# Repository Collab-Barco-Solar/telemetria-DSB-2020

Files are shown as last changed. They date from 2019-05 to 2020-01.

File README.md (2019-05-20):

# telemetria-barco
The codes of a competition boat

Using a TTGO T-Beam Esp 32 with LoRa communication, WiFi, Bluetooth and GPS capabilities.

This repository contains the codes of a project in progress

The Arduino LoRa library utilized is the sandeepmistry arduino LoRa at: https://github.com/sandeepmistry/arduino-LoRa
The ESP32 Arduino library utilized is the espressif arduino-esp32 at: https://github.com/espressif/arduino-esp32 with a guide on how to run it here: https://github.com/espressif/arduino-esp32/blob/master/docs/arduino-ide/boards_manager.md

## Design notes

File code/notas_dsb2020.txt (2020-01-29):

- LEMBRAR DE FAZER TABELA DE RENDIMENTOS DO MOTOR E BUSCAR  MAXIMO RENDIMENTO TEÓRICO;
- Jogar a funcao de desenhar numeros grandes numa biblioteca;
- Descobrir a expressao que descreve carga na bateria em funcao da tensao;
- Criar nocao de tempo para o controlador por biblioteca;

Conector medicoes caixa de circuitos:

- Bat aux - amarelo.
- Bat banco - laranja
- PV in - vermelho

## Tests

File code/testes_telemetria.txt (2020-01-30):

Notas TELEMETRIA (TESTES)

* FUNCIONAMENTO DO ADS1115 (pode ter morrido)
    - Conferir a funcao BatteryCurrentRead();
    - MotorCurrentRead();

* POTENCIOMETRO
    - Conferir se chega 5V do motor (caso nao, ajustar valor setado em codigo);

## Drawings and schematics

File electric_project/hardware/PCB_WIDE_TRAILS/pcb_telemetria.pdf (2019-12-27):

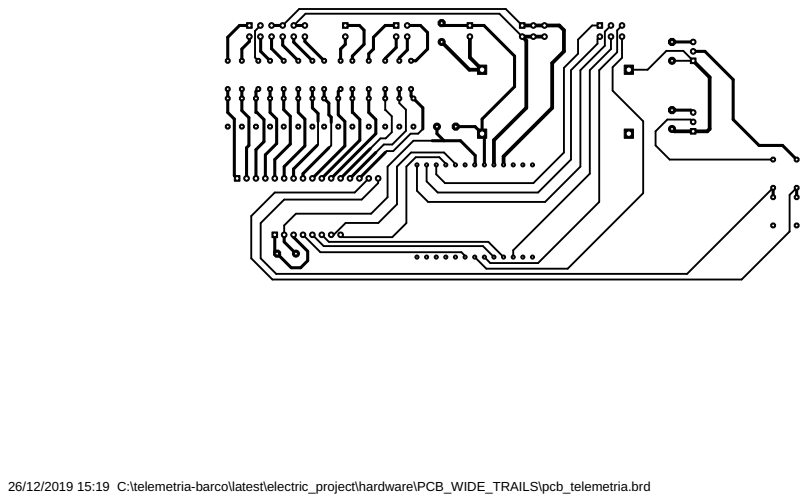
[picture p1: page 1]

26/12/2019 15:19 C:\telemetria-barco\latest\electric_project\hardware\PCB_WIDE_TRAILS\pcb_telemetria.brd

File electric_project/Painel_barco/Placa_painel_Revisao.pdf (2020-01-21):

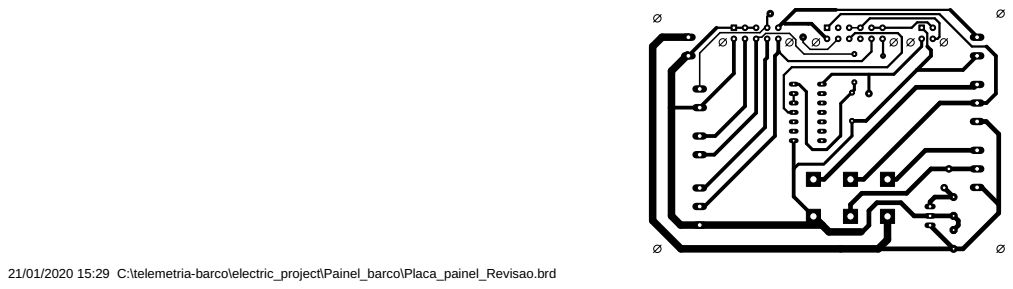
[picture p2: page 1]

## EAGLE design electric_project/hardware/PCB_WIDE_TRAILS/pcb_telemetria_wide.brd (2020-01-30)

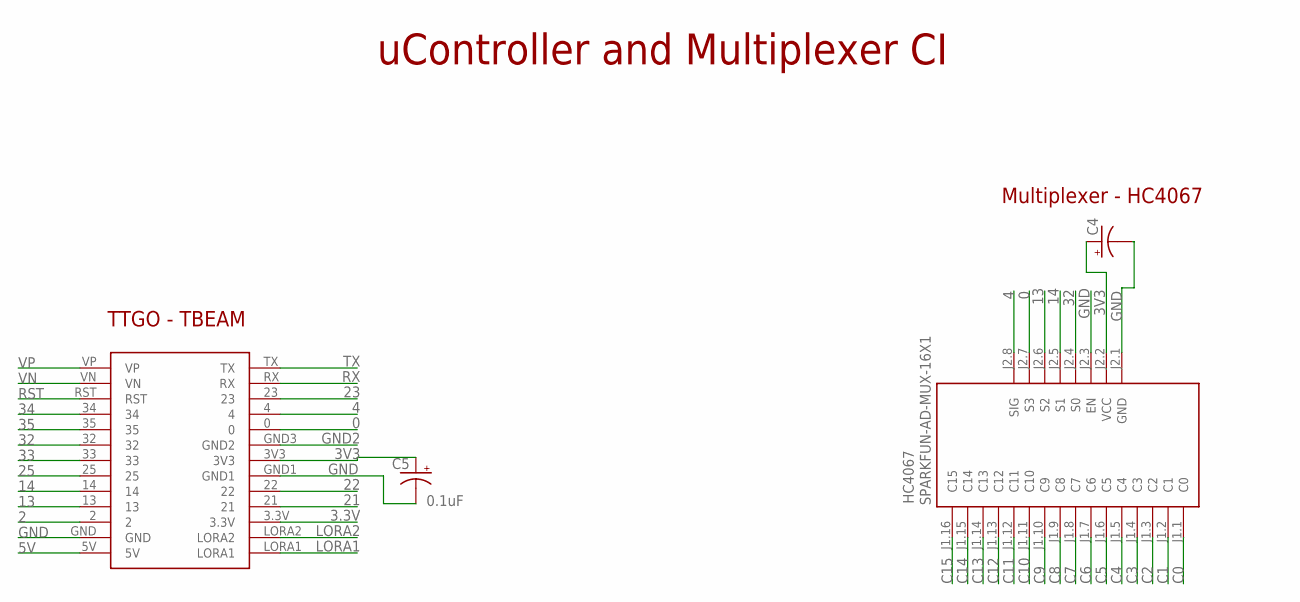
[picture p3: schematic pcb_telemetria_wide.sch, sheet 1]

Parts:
C4: CPOL-USE5-5; E5-5
C5: 0.1uF; E5-5
HC4067: SPARKFUN-AD-MUX-16X1
U$1: TTGOBEAM

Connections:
0: HC4067.J2.7 (S3), U$1.0
2: U$1.2; also elsewhere on the board
3.3V: U$1.3.3V
3V3: C4.+, C5.+, HC4067.J2.2 (VCC), U$1.3V3
4: HC4067.J2.8 (SIG), U$1.4
5V: U$1.5V
13: HC4067.J2.6 (S2), U$1.13
14: HC4067.J2.5 (S1), U$1.14
21: U$1.21; also elsewhere on the board
22: U$1.22; also elsewhere on the board
23: U$1.23; also elsewhere on the board
25: U$1.25; also elsewhere on the board
32: HC4067.J2.4 (S0), U$1.32
33: U$1.33; also elsewhere on the board
34: U$1.34
35: U$1.35
C0: HC4067.J1.1 (C0); also elsewhere on the board
C1: HC4067.J1.2 (C1); also elsewhere on the board
C2: HC4067.J1.3 (C2); also elsewhere on the board
C3: HC4067.J1.4 (C3); also elsewhere on the board
C4: HC4067.J1.5 (C4); also elsewhere on the board
C5: HC4067.J1.6 (C5); also elsewhere on the board
C6: HC4067.J1.7 (C6); also elsewhere on the board
C7: HC4067.J1.8 (C7); also elsewhere on the board
C8: HC4067.J1.9 (C8); also elsewhere on the board
C9: HC4067.J1.10 (C9); also elsewhere on the board
C10: HC4067.J1.11 (C10); also elsewhere on the board
C11: HC4067.J1.12 (C11); also elsewhere on the board
C12: HC4067.J1.13 (C12); also elsewhere on the board
C13: HC4067.J1.14 (C13); also elsewhere on the board
C14: HC4067.J1.15 (C14); also elsewhere on the board
C15: HC4067.J1.16 (C15); also elsewhere on the board
GND: C4.-, C5.-, HC4067.J2.1 (GND), HC4067.J2.3 (EN), U$1.GND, U$1.GND1; also elsewhere on the board
GND2: U$1.GND3 (GND2)
LORA1: U$1.LORA1
LORA2: U$1.LORA2
RST: U$1.RST
RX: U$1.RX; also elsewhere on the board
TX: U$1.TX; also elsewhere on the board
VN: U$1.VN
VP: U$1.VP

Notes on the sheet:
uController and Multiplexer CI
TTGO - TBEAM
Multiplexer - HC4067

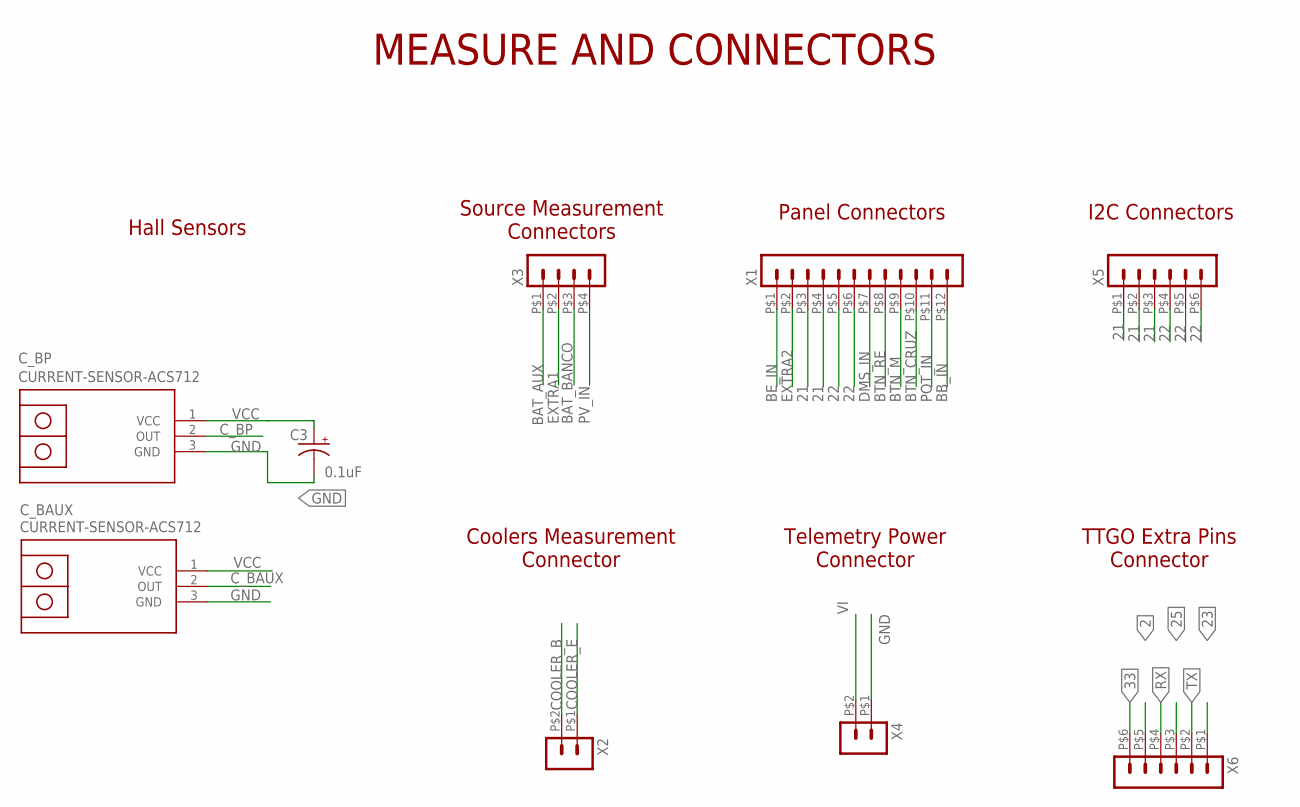
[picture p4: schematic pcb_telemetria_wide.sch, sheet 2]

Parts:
C3: 0.1uF; E5-5
C_BAUX: CURRENT-SENSOR-ACS712
C_BP: CURRENT-SENSOR-ACS712
X1: HEADER_POS12_43045-1212; 43045-1212
X2, X4: HEADER_POS2_43045-0212; 43045-0212
X3: HEADER_POS4_43045-0412; 43045-0412
X5, X6: HEADER_POS6_43045-0612; 43045-0612

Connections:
2: X6.P$5 (5); also elsewhere on the board
21: X1.P$3 (3), X1.P$4 (4), X5.P$1 (1), X5.P$2 (2), X5.P$3 (3); also elsewhere on the board
22: X1.P$5 (5), X1.P$6 (6), X5.P$4 (4), X5.P$5 (5), X5.P$6 (6); also elsewhere on the board
23: X6.P$1 (1); also elsewhere on the board
25: X6.P$3 (3); also elsewhere on the board
33: X6.P$6 (6); also elsewhere on the board
BAT_AUX: X3.P$1 (1); also elsewhere on the board
BAT_BANCO: X3.P$3 (3); also elsewhere on the board
BB_IN: X1.P$12 (12); also elsewhere on the board
BE_IN: X1.P$1 (1); also elsewhere on the board
BTN_CRUZ: X1.P$10 (10); also elsewhere on the board
BTN_M: X1.P$9 (9); also elsewhere on the board
BTN_RE: X1.P$8 (8); also elsewhere on the board
COOLER_B: X2.P$2 (2); also elsewhere on the board
COOLER_E: X2.P$1 (1); also elsewhere on the board
C_BAUX: C_BAUX.2 (OUT); also elsewhere on the board
C_BP: C_BP.2 (OUT); also elsewhere on the board
DMS_IN: X1.P$7 (7); also elsewhere on the board
EXTRA1: X3.P$2 (2); also elsewhere on the board
EXTRA2: X1.P$2 (2); also elsewhere on the board
GND: C3.-, C_BAUX.3 (GND), C_BP.3 (GND), X4.P$1 (1); also elsewhere on the board
POT_IN: X1.P$11 (11); also elsewhere on the board
PV_IN: X3.P$4 (4); also elsewhere on the board
RX: X6.P$4 (4); also elsewhere on the board
TX: X6.P$2 (2); also elsewhere on the board
VCC: C3.+, C_BAUX.1 (VCC), C_BP.1 (VCC); also elsewhere on the board
VI: X4.P$2 (2); also elsewhere on the board

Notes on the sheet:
MEASURE AND CONNECTORS
Hall Sensors
Source Measurement Connectors
I2C Connectors
Panel Connectors
Coolers Measurement Connector
Telemetry Power Connector
TTGO Extra Pins Connector

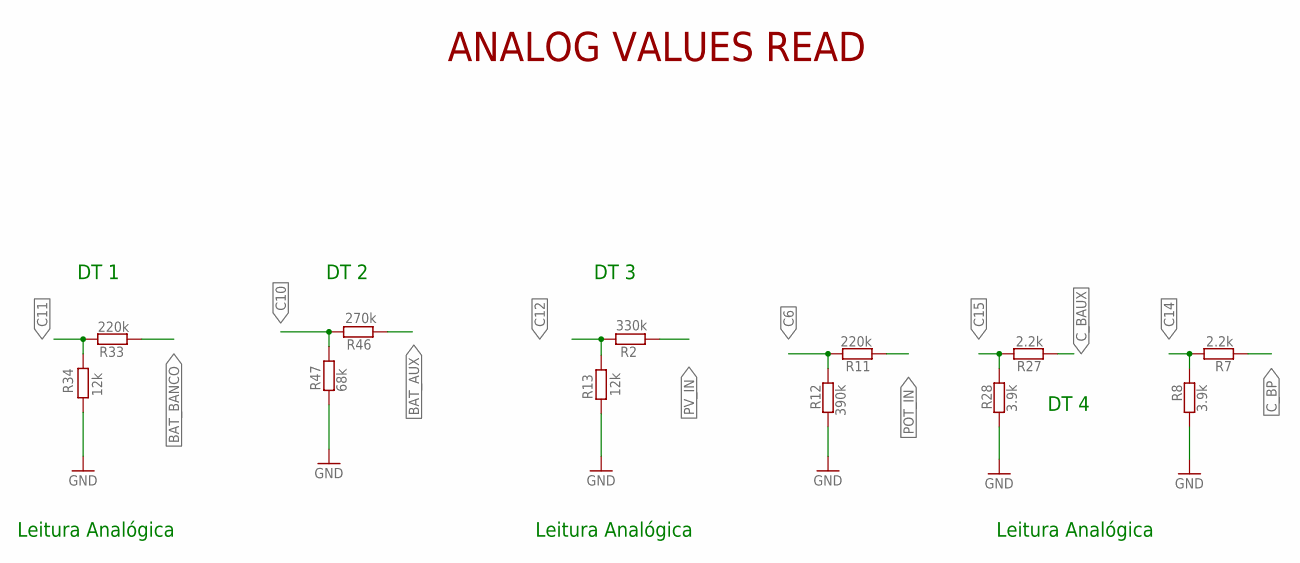
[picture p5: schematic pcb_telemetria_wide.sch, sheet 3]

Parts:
R2: 330k; 0204/7
R7, R27: 2.2k; 0204/7
R8, R28: 3.9k; 0204/7
R11, R33: 220k; 0204/7
R12: 390k; 0204/7
R13, R34: 12k; 0204/7
R46: 270k; 0204/7
R47: 68k; 0204/7

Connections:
BAT_AUX: R46.2; also elsewhere on the board
BAT_BANCO: R33.2; also elsewhere on the board
C6: R11.2, R12.1; also elsewhere on the board
C10: R46.1, R47.2; also elsewhere on the board
C11: R33.1, R34.2; also elsewhere on the board
C12: R2.1, R13.2; also elsewhere on the board
C14: R7.2, R8.1; also elsewhere on the board
C15: R27.2, R28.1; also elsewhere on the board
C_BAUX: R27.1; also elsewhere on the board
C_BP: R7.1; also elsewhere on the board
GND: R8.2, R12.2, R13.1, R28.2, R34.1, R47.1; also elsewhere on the board
POT_IN: R11.1; also elsewhere on the board
PV_IN: R2.2; also elsewhere on the board

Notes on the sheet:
ANALOG VALUES READ
Leitura Analógica
DT 1
DT 3
DT 4
DT 2

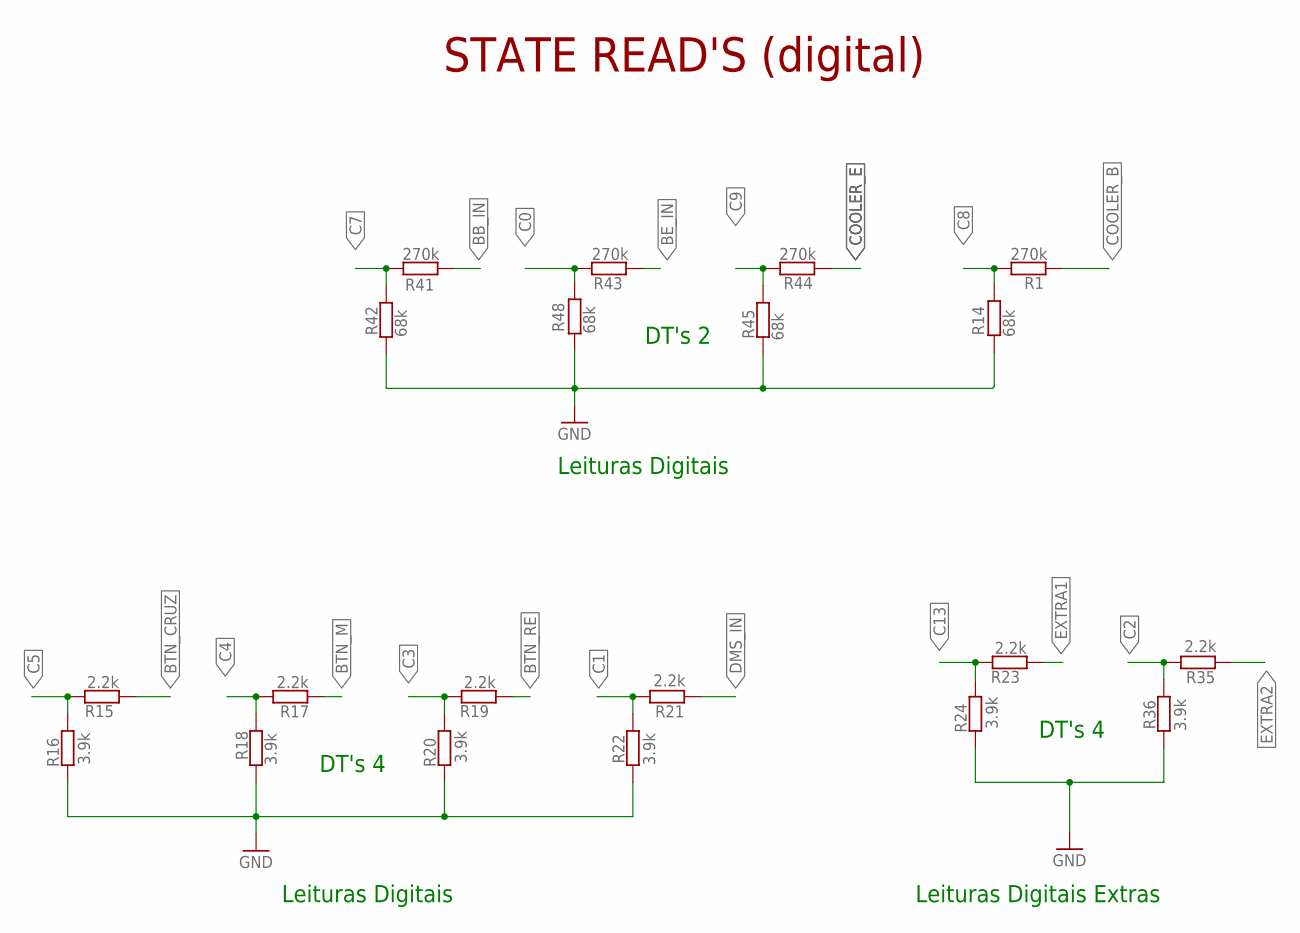
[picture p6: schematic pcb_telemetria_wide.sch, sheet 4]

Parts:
R1, R41, R43, R44: 270k; 0204/7
R14, R42, R45, R48: 68k; 0204/7
R15, R17, R19, R21, R23, R35: 2.2k; 0204/7
R16, R18, R20, R22, R24, R36: 3.9k; 0204/7

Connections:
BB_IN: R41.1; also elsewhere on the board
BE_IN: R43.2; also elsewhere on the board
BTN_CRUZ: R15.1; also elsewhere on the board
BTN_M: R17.2; also elsewhere on the board
BTN_RE: R19.1; also elsewhere on the board
C0: R43.1, R48.1; also elsewhere on the board
C1: R21.1, R22.2; also elsewhere on the board
C2: R35.1, R36.2; also elsewhere on the board
C3: R19.2, R20.1; also elsewhere on the board
C4: R17.1, R18.2; also elsewhere on the board
C5: R15.2, R16.1; also elsewhere on the board
C7: R41.2, R42.1; also elsewhere on the board
C8: R1.2, R14.2; also elsewhere on the board
C9: R44.2, R45.1; also elsewhere on the board
C13: R23.2, R24.1; also elsewhere on the board
COOLER_B: R1.1; also elsewhere on the board
COOLER_E: R44.1; also elsewhere on the board
DMS_IN: R21.2; also elsewhere on the board
EXTRA1: R23.1; also elsewhere on the board
EXTRA2: R35.2; also elsewhere on the board
GND: R14.1, R16.2, R18.1, R20.2, R22.1, R24.2, R36.1, R42.2, R45.2, R48.2; also elsewhere on the board

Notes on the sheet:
STATE READ'S (digital)
Leituras Digitais
DT's 2
Leituras Digitais Extras
DT's 4

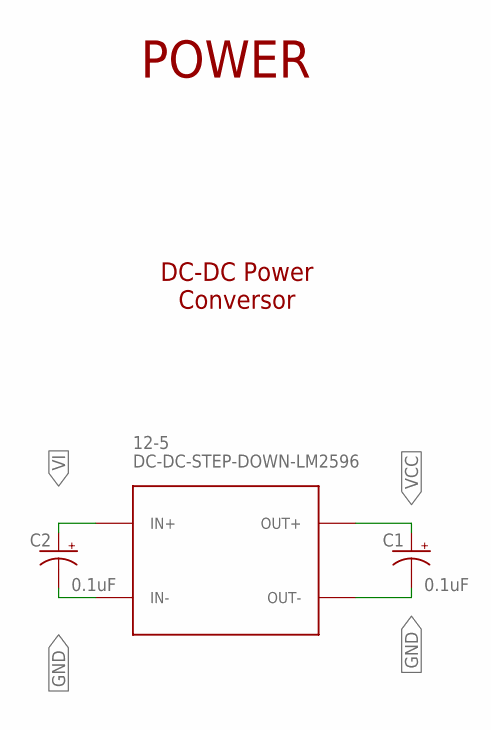
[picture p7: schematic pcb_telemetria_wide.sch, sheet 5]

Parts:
12-5: DC-DC-STEP-DOWN-LM2596
C1, C2: 0.1uF; E5-5

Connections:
GND: 12-5.IN-, 12-5.OUT-, C1.-, C2.-; also elsewhere on the board
VCC: 12-5.OUT+, C1.+; also elsewhere on the board
VI: 12-5.IN+, C2.+; also elsewhere on the board

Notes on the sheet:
POWER
DC-DC Power Conversor

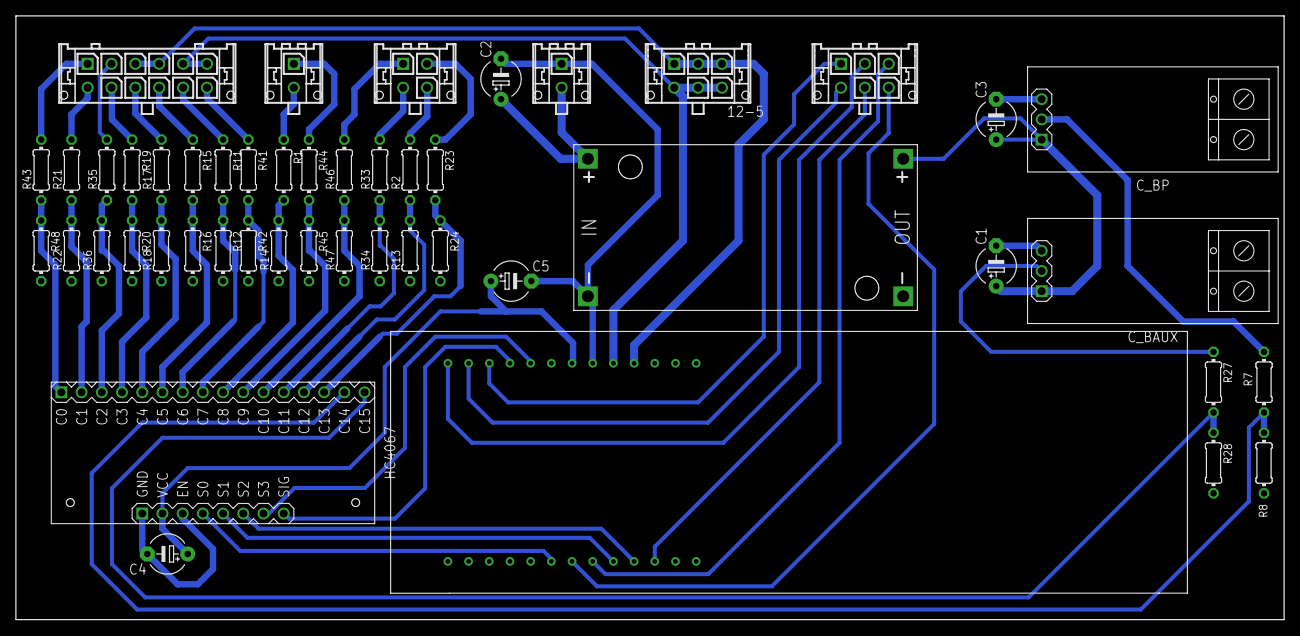
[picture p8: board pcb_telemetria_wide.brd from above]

Board: 2 copper layers, 159.4 x 75.9 mm, 48 parts (0 on the bottom side), 49 nets.

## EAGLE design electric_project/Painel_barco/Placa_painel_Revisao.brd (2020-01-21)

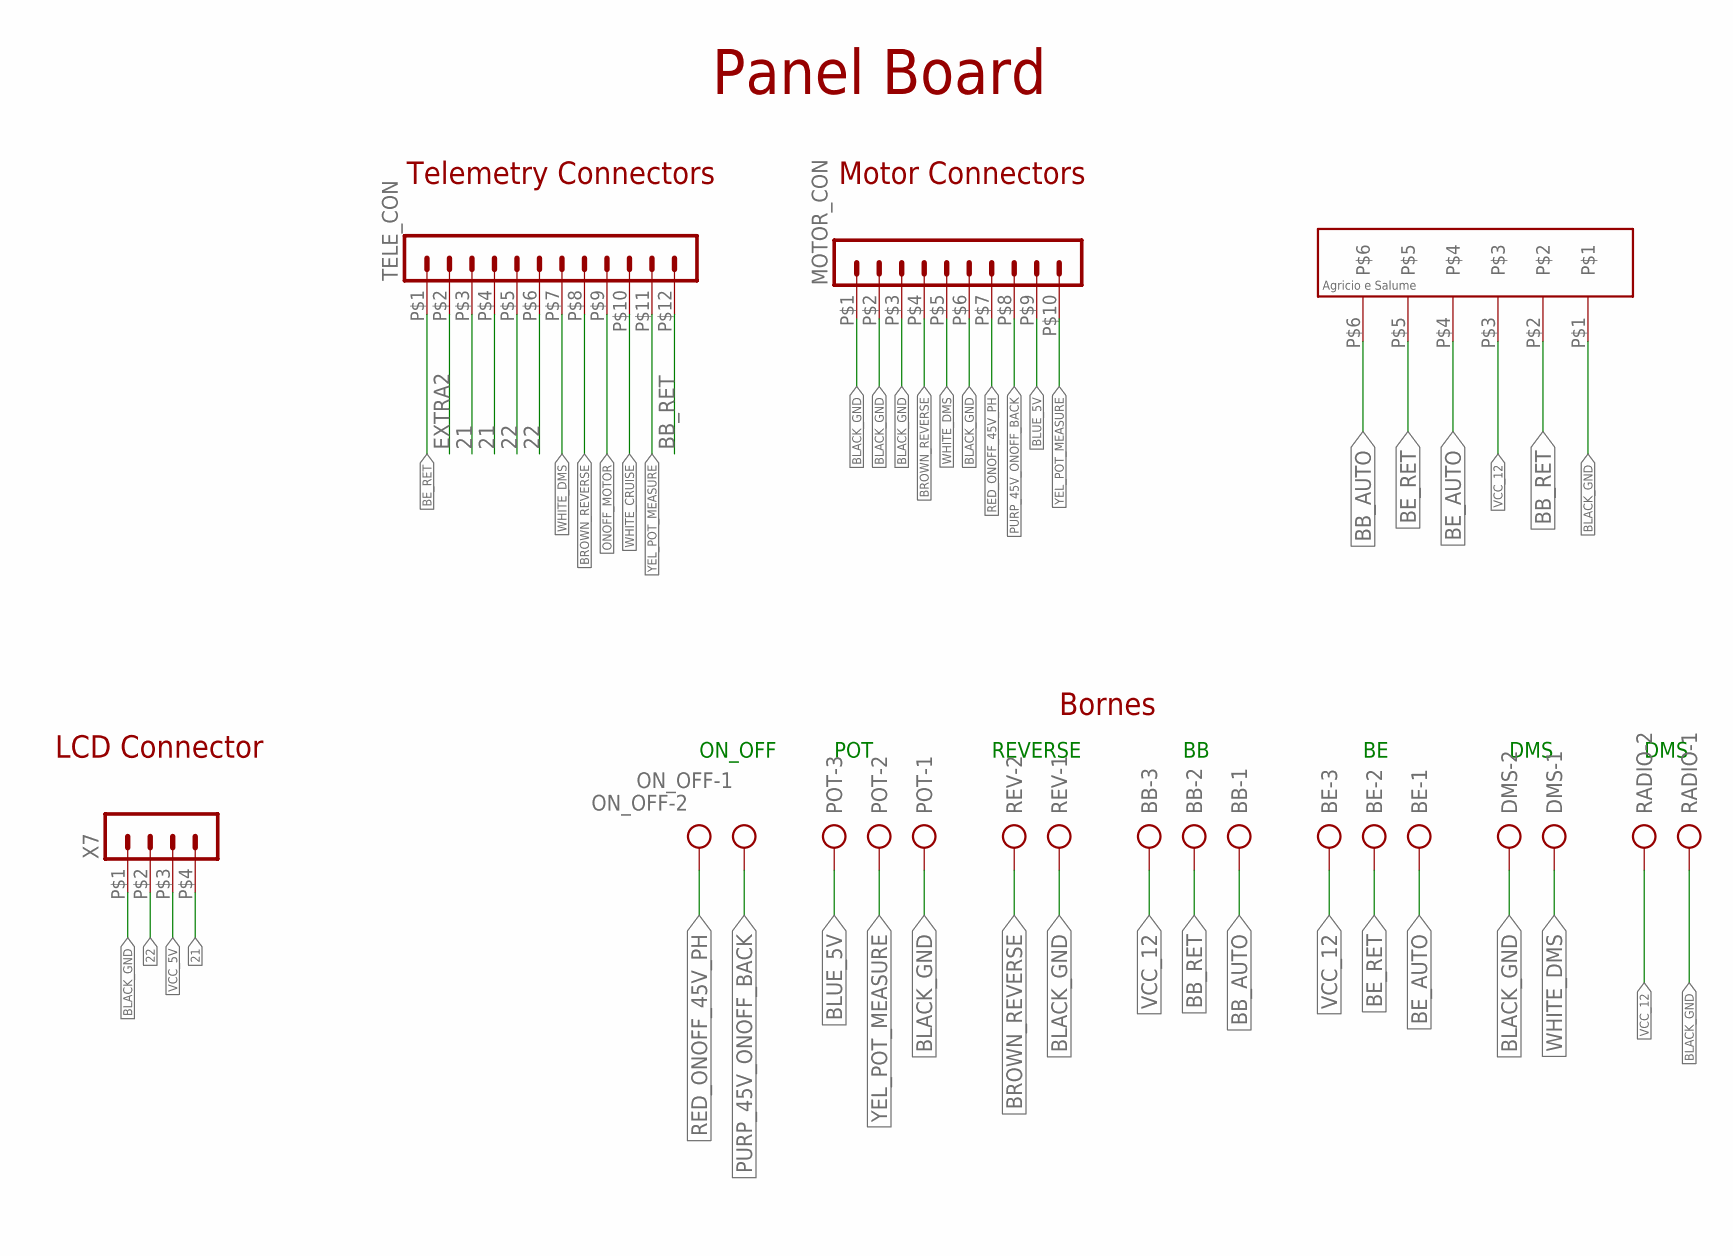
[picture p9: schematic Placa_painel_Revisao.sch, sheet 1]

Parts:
BB: AK500/3
BE: AK500/3
DMS: AK500/2
MOTOR_CON: HEADER_POS10_43045-1012; 43045-1012
ON_OFF: AK500/2
POT: AK500/3
RADIO: AK500/2
REV: AK500/2
TELE_CON: HEADER_POS12_43045-1212; 43045-1212
U$1: CON_HOLE; CON_HOLE_6
X7: HEADER_POS4_43045-0412; 43045-0412

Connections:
21: TELE_CON.P$3 (3), TELE_CON.P$4 (4), X7.P$4 (4)
22: TELE_CON.P$5 (5), TELE_CON.P$6 (6), X7.P$2 (2)
BB_AUTO: BB.1, U$1.P$6
BB_RET: BB.2, TELE_CON.P$12 (12), U$1.P$2
BE_AUTO: BE.1, U$1.P$4
BE_RET: BE.2, TELE_CON.P$1 (1), U$1.P$5
BLACK_GND: DMS.2, MOTOR_CON.P$1 (1), MOTOR_CON.P$2 (2), MOTOR_CON.P$3 (3), MOTOR_CON.P$6 (6), POT.1, RADIO.1, REV.1, U$1.P$1, X7.P$1 (1); also elsewhere on the board
BLUE_5V: MOTOR_CON.P$9 (9), POT.3
BROWN_REVERSE: MOTOR_CON.P$4 (4), REV.2, TELE_CON.P$8 (8)
EXTRA2: TELE_CON.P$2 (2)
ONOFF_MOTOR: TELE_CON.P$9 (9); also elsewhere on the board
PURP_45V_ONOFF_BACK: MOTOR_CON.P$8 (8), ON_OFF.1; also elsewhere on the board
RED_ONOFF_45V_PH: MOTOR_CON.P$7 (7), ON_OFF.2
VCC_5V: X7.P$3 (3); also elsewhere on the board
VCC_12: BB.3, BE.3, RADIO.2, U$1.P$3; also elsewhere on the board
WHITE_CRUISE: TELE_CON.P$10 (10)
WHITE_DMS: DMS.1, MOTOR_CON.P$5 (5), TELE_CON.P$7 (7)
YEL_POT_MEASURE: MOTOR_CON.P$10 (10), POT.2, TELE_CON.P$11 (11)

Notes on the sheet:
Panel Board
Telemetry Connectors
Motor Connectors
LCD Connector
Bornes
ON_OFF
POT
REVERSE
DMS

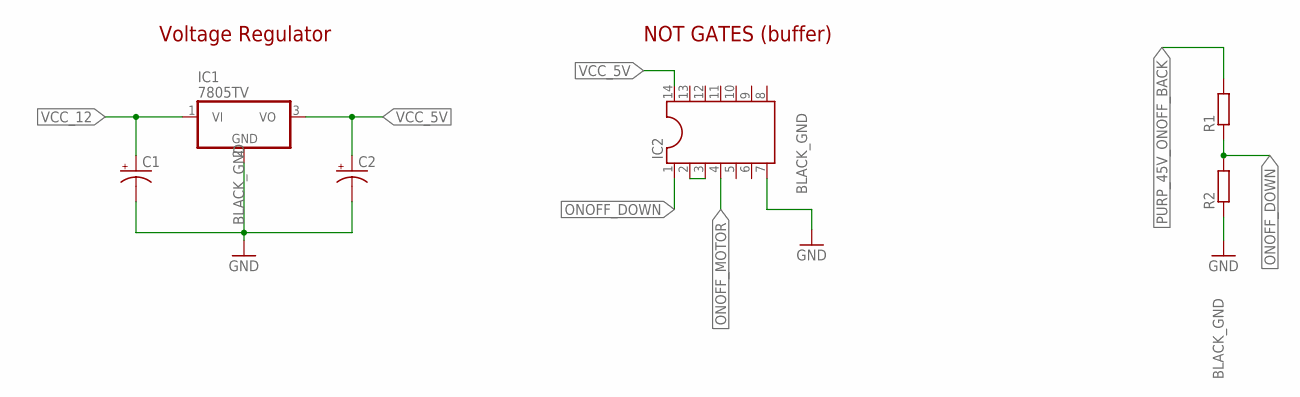
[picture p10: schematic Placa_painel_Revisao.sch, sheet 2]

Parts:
C1, C2: CPOL-USE5-5; E5-5
IC1: 7805TV; TO220V
IC2: DIL14
R1, R2: R-EU_0204/7; 0204/7

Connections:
BLACK_GND: C1.-, C2.-, IC1.2 (GND), IC2.7, R2.1; also elsewhere on the board
unnamed: IC2.2, IC2.3
ONOFF_DOWN: IC2.1, R1.1, R2.2
ONOFF_MOTOR: IC2.4; also elsewhere on the board
PURP_45V_ONOFF_BACK: R1.2; also elsewhere on the board
VCC_5V: C2.+, IC1.3 (VO), IC2.14; also elsewhere on the board
VCC_12: C1.+, IC1.1 (VI); also elsewhere on the board

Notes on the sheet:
Voltage Regulator
NOT GATES (buffer)

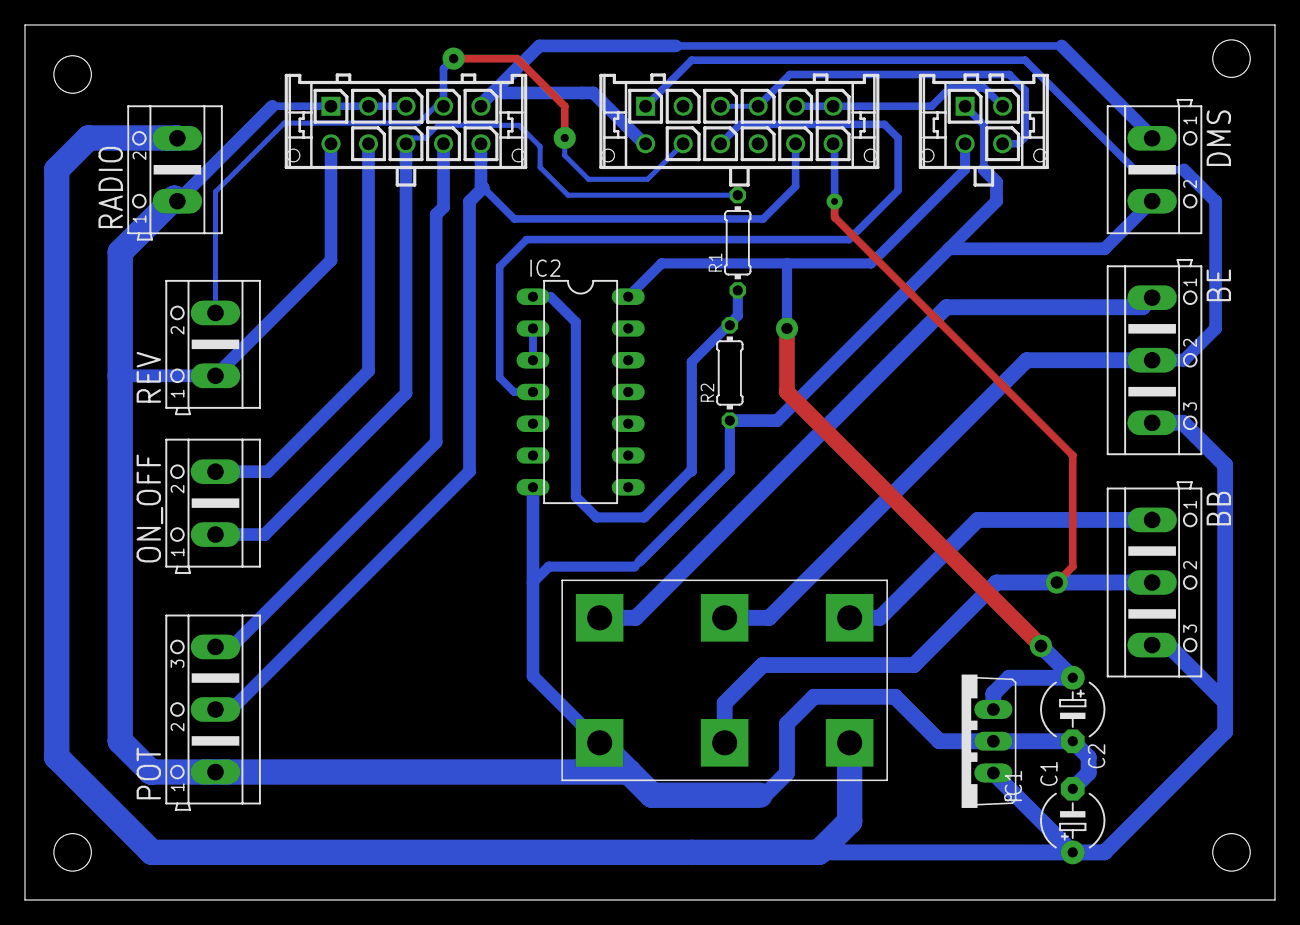
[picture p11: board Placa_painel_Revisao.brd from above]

Board: 2 copper layers, 100.0 x 70.0 mm, 17 parts (0 on the bottom side), 18 nets.

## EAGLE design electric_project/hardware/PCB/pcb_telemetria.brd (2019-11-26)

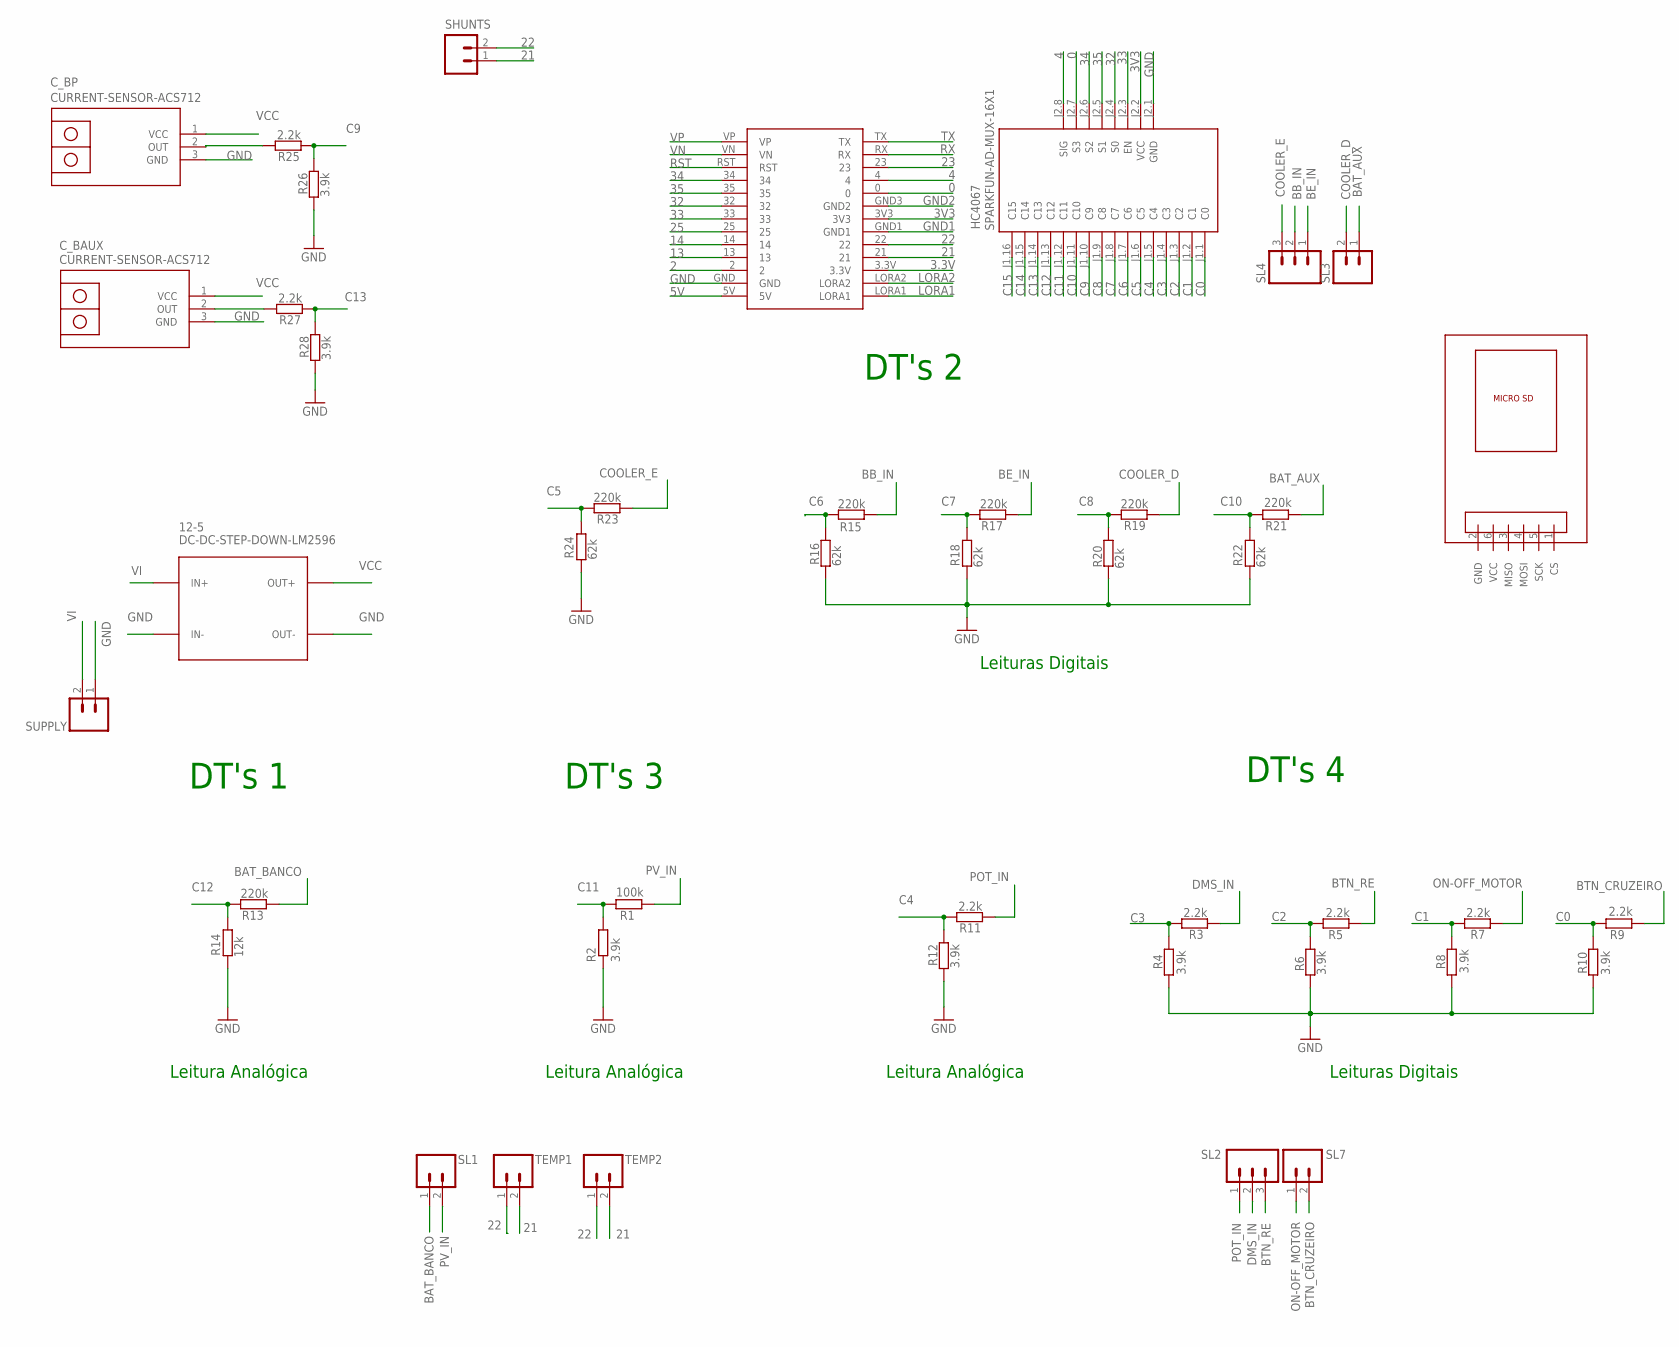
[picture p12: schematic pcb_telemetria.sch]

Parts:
12-5: DC-DC-STEP-DOWN-LM2596
C_BAUX: CURRENT-SENSOR-ACS712
C_BP: CURRENT-SENSOR-ACS712
HC4067: SPARKFUN-AD-MUX-16X1
R1: 100k; 0204/7
R2, R4, R6, R8, R10, R12, R26, R28: 3.9k; 0204/7
R3, R5, R7, R9, R11, R25, R27: 2.2k; 0204/7
R13, R15, R17, R19, R21, R23: 220k; 0204/7
R14: 12k; 0204/7
R16, R18, R20, R22, R24: 62k; 0204/7
SHUNTS: M02; 02P
SL1, SL3, SL7: M02; 02P
SL2, SL4: M03; 03P
SUPPLY: M02; 02P
TEMP1, TEMP2: M02; 02P
U$1: TTGOBEAM
U$2: MICRO_SD_MODULE; MICRO_SD

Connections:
0: HC4067.J2.7 (S3), U$1.0
2: U$1.2
3.3V: U$1.3.3V
3V3: HC4067.J2.2 (VCC), U$1.3V3
4: HC4067.J2.8 (SIG), U$1.4
5V: U$1.5V
13: U$1.13
14: U$1.14
21: SHUNTS.1, TEMP1.2, TEMP2.2, U$1.21
22: SHUNTS.2, TEMP1.1, TEMP2.1, U$1.22
23: U$1.23
25: U$1.25
32: HC4067.J2.4 (S0), U$1.32
33: HC4067.J2.3 (EN), U$1.33
34: HC4067.J2.6 (S2), U$1.34
35: HC4067.J2.5 (S1), U$1.35
BAT_AUX: R21.2, SL3.1
BAT_BANCO: R13.2, SL1.1
BB_IN: R15.1, SL4.2
BE_IN: R17.2, SL4.1
BTN_CRUZEIRO: R9.2, SL7.2
BTN_RE: R5.2, SL2.3
C0: HC4067.J1.1 (C0), R9.1, R10.2
C1: HC4067.J1.2 (C1), R7.2, R8.1
C2: HC4067.J1.3 (C2), R5.1, R6.2
C3: HC4067.J1.4 (C3), R3.2, R4.1
C4: HC4067.J1.5 (C4), R11.2, R12.1
C5: HC4067.J1.6 (C5), R23.2, R24.1
C6: HC4067.J1.7 (C6), R15.2, R16.1
C7: HC4067.J1.8 (C7), R17.1, R18.2
C8: HC4067.J1.9 (C8), R19.2, R20.1
C9: HC4067.J1.10 (C9), R25.1, R26.1
C10: HC4067.J1.11 (C10), R21.1, R22.2
C11: HC4067.J1.12 (C11), R1.1, R2.2
C12: HC4067.J1.13 (C12), R13.1, R14.2
C13: HC4067.J1.14 (C13), R27.1, R28.1
C14: HC4067.J1.15 (C14)
C15: HC4067.J1.16 (C15)
COOLER_D: R19.1, SL3.2
COOLER_E: R23.1, SL4.3
DMS_IN: R3.1, SL2.2
GND: 12-5.IN-, 12-5.OUT-, C_BAUX.3 (GND), C_BP.3 (GND), HC4067.J2.1 (GND), R2.1, R4.2, R6.1, R8.2, R10.1, R12.2, R14.1, R16.2, R18.1, R20.2, R22.1, R24.2, R26.2, R28.2, SUPPLY.1, U$1.GND
GND1: U$1.GND1
GND2: U$1.GND3 (GND2)
LORA1: U$1.LORA1
LORA2: U$1.LORA2
unnamed: C_BP.2 (OUT), R25.2
unnamed: C_BAUX.2 (OUT), R27.2
ON-OFF_MOTOR: R7.1, SL7.1
POT_IN: R11.1, SL2.1
PV_IN: R1.2, SL1.2
RST: U$1.RST
RX: U$1.RX
TX: U$1.TX
VCC: 12-5.OUT+, C_BAUX.1 (VCC), C_BP.1 (VCC)
VI: 12-5.IN+, SUPPLY.2
VN: U$1.VN
VP: U$1.VP

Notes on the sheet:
Leituras Digitais
Leitura Analógica
DT's 4
DT's 3
DT's 1
DT's 2

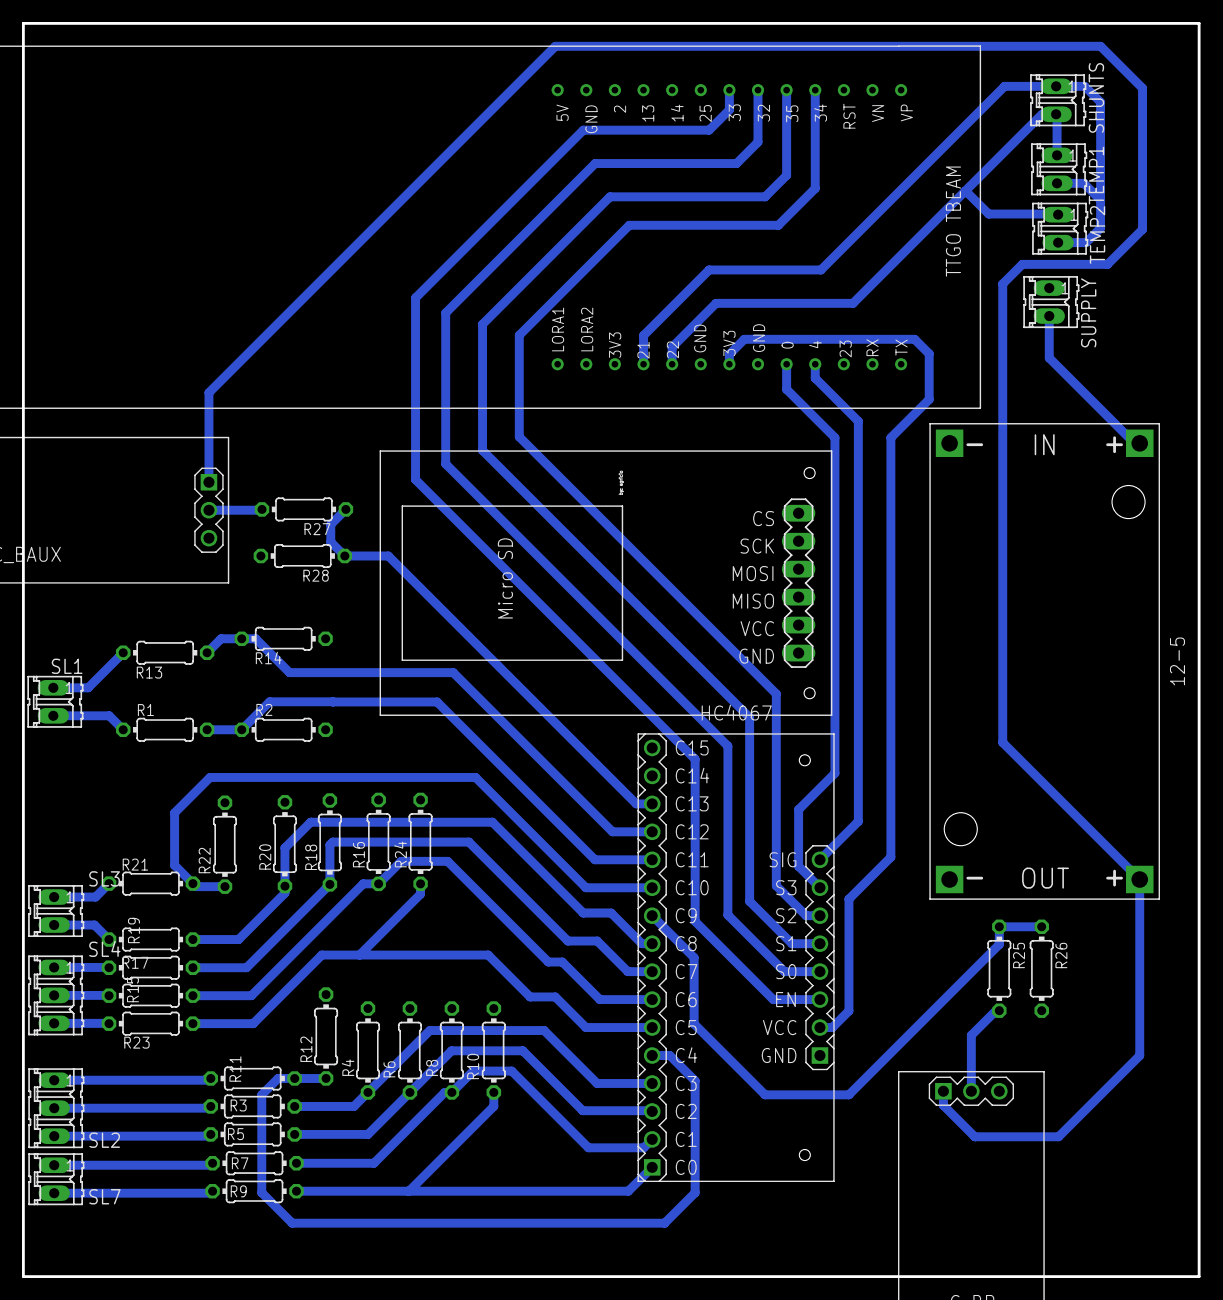
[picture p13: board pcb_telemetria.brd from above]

Board: 2 copper layers, 106.8 x 113.8 mm, 43 parts (0 on the bottom side), 40 nets.

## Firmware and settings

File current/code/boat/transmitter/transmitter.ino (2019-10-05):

// bibliotecas

#include <SPI.h>
#include <LoRa.h>
#include <Wire.h>
#include <TinyGPS++.h>
#include <HardwareSerial.h>
#include <Adafruit_ADS1015.h>


//pinos

#define SCK     5     // GPIO5  -- LoRa SX1278's SCK
#define MISO    19    // GPIO19 -- LoRa SX1278's MISnO
#define MOSI    27    // GPIO27 -- LoRa SX1278's MOSI
#define SS      18    // GPIO18 -- LoRa SX1278's CS
#define RST     14    // GPIO14 -- LoRa SX1278's RESET
#define DI0     26    // GPIO26 -- LoRa SX1278's IRQ(Interrupt Request)

#define RXPin    15  // Neo6M RX pin
#define TXPin    12  // Neo6M TX pin
#define GPSBaud 9600 // Neo6M Baud rate

#define S0 32 //MUX control pins
#define S1 35
#define S2 34
#define S3 0
#define MUX_EN 33 //MUX pin to turn on and off
#define MUX_SIG 4 //MUX input Pin

//#define PIN_ACS 33  //??
//#define PIN_BAT_AUX 13
//#define PIN_POTENCIOMETER 14
//#define PIN_BAT_BANK_V 2
//#define PIN_BAT_BANK_C 21
//#define PIN_MOTOR 22


//defines

#define FREQ  915E6   // Operating LoRa frequency
#define SF      7     // Operating LoRa Spread Factor
#define BAND  125E3   // Operating LoRa Bandwidth
#define TXPOWER 20    // Operating LoRa Transmition Power
#define BAUD 2000000  // BAUD serial rate


#define MOTOR    0x48  // Address of the ADC measuring the motor current
#define BATTERY  0x49  // Address of the ADC on the solar panel modules


//Conversion Ratios (Voltage Divider)

float DT1_RATIO = 19.333333333f;
float DT2_RATIO = 4.970588235f;
float DT3_RATIO = 28.5f;
float DT4_RATIO = 1.564102564f;

//objetos

String rssi = "RSSI --";
String packSize = "--";
String packet ;

TinyGPSPlus gps;      // GPS object
HardwareSerial ss(2); // Hardware Serial comunication object

Adafruit_ADS1115 ads_motor(MOTOR);
Adafruit_ADS1115 ads_battery(BATTERY);

//MUX Selecting Channels
int MUX_CH[16][4] = {(0,0,0,0), //Channel 0
                     (1,0,0,0), //Channel 1
                     (0,1,0,0), //Channel 2
                     (1,1,0,0), //Channel 3
                     (0,0,1,0), //Channel 4
                     (1,0,1,0), //Channel 5
                     (0,1,1,0), //Channel 6
                     (1,1,1,0), //Channel 7
                     (0,0,0,1), //Channel 8
                     (1,0,0,1), //Channel 9
                     (0,1,0,1), //Channel 10
                     (1,1,0,1), //Channel 11
                     (0,0,1,1), //Channel 12
                     (1,0,1,1), //Channel 13
                     (0,1,1,1), //Channel 14
                     (1,1,1,1)}; //Channel 15


  //   Cheatsheet                                                     ADS1115
  //                                                                  -------
  // ads.setGain(GAIN_TWOTHIRDS);  // 2/3x gain +/- 6.144V  1 bit =   0.1875mV (default)
  // ads.setGain(GAIN_ONE);        // 1x gain   +/- 4.096V  1 bit =   0.125mV
  // ads.setGain(GAIN_TWO);        // 2x gain   +/- 2.048V  1 bit =   0.0625mV
  // ads.setGain(GAIN_FOUR);       // 4x gain   +/- 1.024V  1 bit =   0.03125mV
  // ads.setGain(GAIN_EIGHT);      // 8x gain   +/- 0.512V  1 bit =   0.015625mV
  // ads.setGain(GAIN_SIXTEEN);    // 16x gain  +/- 0.256V  1 bit =   0.0078125mV

//functions

void SetMuxChannel(int ChannelOrder[]){
  digitalWrite(S0, ChannelOrder[0]);
  digitalWrite(S1, ChannelOrder[1]);
  digitalWrite(S2, ChannelOrder[2]);
  digitalWrite(S3, ChannelOrder[3]);
}

double LatitudeGPS( ){

  return gps.location.lat();
}

double LongitudeGPS( ){
  
  return gps.location.lng();
}

char CSV_Separator(){
  return (' ; ');
}

float MotorCurrentRead(){
  ads_motor.setGain(GAIN_SIXTEEN);    // 16x gain  +/- 0.256V  1 bit =   0.0078125mV
  
  return ads_motor.readADC_Differential_0_1();
}

float BatteryCurrentRead(){
  ads_battery.setGain(GAIN_ONE);        // 1x gain   +/- 4.096V  1 bit =   0.125mV
  
  return ads_battery.readADC_Differential_0_1();
}

float PotentiometerRead(){
  SetMuxChannel(MUX_CH[4]);
  float readVoltage = (analogRead(MUX_SIG) * 3.3) / 1024;  //if analog read == 1024, it is reading 3.3V, so convert the reading from bits to Voltage
  
  return readVoltage * DT4_RATIO * 2; //Multiply by the ratio of the voltage divider to find the true voltage value
}

boolean DmsRead(){
  SetMuxChannel(MUX_CH[0]); 
  return (analogRead(MUX_SIG) < 300); //If it's less than 300 bits, then consider the button as closed and dms on
}

boolean ButtonReverseRead(){
  SetMuxChannel(MUX_CH[1]);
  
  return (analogRead(MUX_SIG) < 300); //If it's less than 300 bits, then consider the button as closed
}

boolean ButtonMotorRead(){
  SetMuxChannel(MUX_CH[2]);
  
  return (analogRead(MUX_SIG) < 300); //If it's less than 300 bits, then consider the button as closed
}

boolean ButtonCruiseRead(){
  SetMuxChannel(MUX_CH[3]);
  
  return (analogRead(MUX_SIG) < 300); //If it's less than 300 bits, then consider the button as closed
}

float CoolerLeftRead(){
  SetMuxChannel(MUX_CH[5]);
  float readVoltage = (analogRead(MUX_SIG) * 3.3) / 1024;  //if analog read == 1024, it is reading 3.3V, so convert the reading from bits to Voltage
  
  return readVoltage * DT2_RATIO; //Multiply by the ratio of the voltage divider to find the true voltage value
}

float CoolerRightRead(){
  SetMuxChannel(MUX_CH[8]);
  float readVoltage = (analogRead(MUX_SIG) * 3.3) / 1024;  //if analog read == 1024, it is reading 3.3V, so convert the reading from bits to Voltage
  
  return readVoltage * DT2_RATIO; //Multiply by the ratio of the voltage divider to find the true voltage value
}
float AuxiliaryBatteryRead(){
  SetMuxChannel(MUX_CH[10]);
  float readVoltage = (analogRead(MUX_SIG) * 3.3) / 1024;  //if analog read == 1024, it is reading 3.3V, so convert the reading from bits to Voltage
  
  return readVoltage * DT2_RATIO; //Multiply by the ratio of the voltage divider to find the true voltage value
}
float AuxiliaryBatteryCurrentRead(){
  SetMuxChannel(MUX_CH[9]);
  float readVoltage = (analogRead(MUX_SIG) * 3.3) / 1024;  //if analog read == 1024, it is reading 3.3V, so convert the reading from bits to Voltage
  
  return readVoltage * DT4_RATIO; //Multiply by the ratio of the voltage divider to find the true voltage value
}

float PhotovoltaicModulesRead(){
  SetMuxChannel(MUX_CH[11]);
  float readVoltage = (analogRead(MUX_SIG) * 3.3) / 1024;  //if analog read == 1024, it is reading 3.3V, so convert the reading from bits to Voltage
  
  return readVoltage * DT3_RATIO; //Multiply by the ratio of the voltage divider to find the true voltage value
}

float BatteryBankRead(){
  SetMuxChannel(MUX_CH[12]);
  float readVoltage = (analogRead(MUX_SIG) * 3.3) / 1024;  //if analog read == 1024, it is reading 3.3V, so convert the reading from bits to Voltage
  
  return readVoltage * DT1_RATIO; //Multiply by the ratio of the voltage divider to find the true voltage value
}

boolean LeftPumpRead(){
  SetMuxChannel(MUX_CH[6]);
  
  return (analogRead(MUX_SIG) < 300); //If it's less than 300 bits, then consider the button as closed
}

boolean RightPumpRead(){
  SetMuxChannel(MUX_CH[7]);
    
  return (analogRead(MUX_SIG) < 300); //If it's less than 300 bits, then consider the button as closed
}


//setup

void setup() {
  
  Serial.begin(BAUD);
  ss.begin(GPSBaud, SERIAL_8N1, TXPin, RXPin); // GPS serial communication

  //pinMode(PIN_POTENCIOMETER, INPUT);
  //MUX pins
  pinMode(S0, OUTPUT);
  pinMode(S1, OUTPUT);
  pinMode(S2, OUTPUT);
  pinMode(S3, OUTPUT);
  pinMode(MUX_EN, OUTPUT);
  pinMode(MUX_SIG, INPUT);

  digitalWrite(S0, LOW);
  digitalWrite(S1, LOW);
  digitalWrite(S2, LOW);
  digitalWrite(S3, LOW);
  digitalWrite(MUX_EN,LOW);
  
  while (!Serial);
  Serial.println();
  Serial.println("Boat sender");
  
  SPI.begin(SCK,MISO,MOSI,SS); // LoRa SPI communication
  LoRa.setPins(SS,RST,DI0);
  
  if (!LoRa.begin(FREQ)) {
    Serial.println("Starting LoRa failed!");
    while (1);
  }

  LoRa.setSpreadingFactor(SF);
  LoRa.setSignalBandwidth(BAND);
  LoRa.setTxPower(TXPOWER);
  LoRa.enableCrc();

  
  //LoRa.onReceive(cbk);
  //  LoRa.receive();
  Serial.println("Initialization: ok");
 
  delay(1500);
}

void loop() {
  
  // Create and send packet

  // Update GPS
//  gps.encode(ss.read());
//  
//  LoRa.beginPacket();
//  // Write GPS Latitude
//  LoRa.print("GPS.LAT: "); 
//  LoRa.print(LatitudeGPS());
//  LoRa.print(CSV_Separator());
//  // Write GPS Longitude
//  LoRa.print("GPS.LONG: "); 
//  LoRa.print(LongitudeGPS());
//  LoRa.print(CSV_Separator());

  //MUX readings
  
  // Write DMS reading
//  LoRa.print("DMS READ: ");
//  LoRa.print(DmsRead());
//  LoRa.print(CSV_Separator());
//  //Write reverse button (ré)
//  LoRa.print("REVERSE: ");
//  LoRa.print(ButtonReverseRead()); //For all the buttons -> "true" means closed and "false" means open
//  LoRa.print(CSV_Separator());
//  //Write motor button state (on/off)
//  LoRa.print("MOTOR: ");
//  LoRa.print(ButtonMotorRead()); //For all the buttons -> "true" means closed and "false" means open
//  LoRa.print(CSV_Separator());
//  //Write cruise button state
//  LoRa.print("Cruise: ");
//  LoRa.print(ButtonCruiseRead()); //For all the buttons -> "true" means closed and "false" means open
//  LoRa.print(CSV_Separator());
//  // Write Current input in the batteryes voltage  (using the ADS1115)
//  LoRa.print("Bat. Current: ");
//  LoRa.print(BatteryCurrentRead());
//  LoRa.print(CSV_Separator());
  // Write the potentiometer state that controls the motor 
  LoRa.print("Potentiometer: ");
  Serial.print("Potentiometer: ");
  Serial.println(PotentiometerRead());
  LoRa.print(PotentiometerRead());
  LoRa.print(CSV_Separator());
//  // Write Solar Modules voltage
//  LoRa.print("Modules: ");  
//  LoRa.print(PhotovoltaicModulesRead());
//  LoRa.print(CSV_Separator());
//  // Write Auxiliary Battery voltage 
//  LoRa.print("Bat. Aux: ");   
//  LoRa.print(AuxiliaryBatteryRead());
//  LoRa.print(CSV_Separator());
//  // Write Auxiliary Battery current (using acs712) 
//  LoRa.print("Bat.A.C.: "); 
//  LoRa.print(AuxiliaryBatteryCurrentRead());
//  LoRa.print(CSV_Separator());
//  // Write Battery Bank voltage 
//  LoRa.print("Bat.Bank.: ");  
//  LoRa.print(BatteryBankRead());
//  LoRa.print(CSV_Separator());
//  //Write left cooler tension
//  LoRa.print("Cooler.B: ");  
//  LoRa.print(CoolerLeftRead());
//  LoRa.print(CSV_Separator());
//  //Write right cooler tension
//  LoRa.print("Cooler.E: ");  
//  LoRa.print(CoolerRightRead());
//  LoRa.print(CSV_Separator());
//  // Write left pump state
//  LoRa.print("Pump.B: ");  
//  LoRa.print(LeftPumpRead());
//  LoRa.print(CSV_Separator());
//  // Write right pump state
//  LoRa.print("Pump.E: ");  
//  LoRa.print(RightPumpRead());
//  LoRa.print(CSV_Separator());
//
//  // Write Motor Current reading (motor current)
//  LoRa.print("Motor C.: ");
//  LoRa.print(MotorCurrentRead());
//  LoRa.print(CSV_Separator());
//  // Write Battery CurrentIn (probably using the ADS1115)
//  LoRa.print("Bat.C.In: ");
//  LoRa.print(BatteryCurrentRead());
//  LoRa.print(CSV_Separator());
  
  //LoRa.print(counter);
 // LoRa.endPacket();

//  delay(50);
}

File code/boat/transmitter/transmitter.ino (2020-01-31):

 // bibliotecas

#include <SPI.h>
#include <LoRa.h>
#include <Wire.h>
#include <TinyGPS++.h>
#include <HardwareSerial.h>
#include <Adafruit_ADS1015.h>
#include <LiquidCrystal_I2C.h>


//LoRa transmission and GPS pins

#define SCK     5     // GPIO5  -- LoRa SX1278's SCK
#define MISO    19    // GPIO19 -- LoRa SX1278's MISnO
#define MOSI    27    // GPIO27 -- LoRa SX1278's MOSI
#define SS      18    // GPIO18 -- LoRa SX1278's CS
#define RST     14    // GPIO14 -- LoRa SX1278's RESET
#define DI0     26    // GPIO26 -- LoRa SX1278's IRQ(Interrupt Request)

#define RXPin    15  // Neo6M RX pin
#define TXPin    12  // Neo6M TX pin
#define GPSBaud 9600 // Neo6M Baud rate

// Mux defines

#define S0 32 //MUX control pins
#define S1 14
#define S2 13
#define S3 0
#define MUX_SIG 4 //MUX input Pin

// ACS712 defines
const int mVperAmp = 66;
const int acsVoltageOffSet = 2500; // milivolts voltage acsVoltageOffSet
const int acsVoltageInput = 5000; // milivolts voltage

// polynomial coefficients (ADC Adjustment)

const float p5 = 17.5938359490609;
const float p4 = 1.21697808640912;
const float p3 = -0.000168313273959029;
const float p2 =  7.69758075646963e-08;
const float p1 = -1.21956845031952e-11;

char buf[20];
// MUX input pins

int DMSMux = 1;
int ReverseMux = 3;
int OnOffMux = 4;
int CruiseMux = 5;
int PotMux = 6;
int CBMux = 8;
int BBMux = 7;
int BEMux = 0;
int CEMux = 9;
int BatAMux = 10;
int BatBankMux = 11;
int PhotoMux = 12;
int ACS1Mux = 14;
int ACS2Mux = 13;

// Other Variables
float current;

// Not multiplexed pins
#define PIN_BAT_AUX 13
#define PIN_POTENCIOMETER 14
#define PIN_BAT_BANK_V 2
#define PIN_BAT_BANK_C 21
#define PIN_MOTOR 22


// Other defines

#define FREQ  915E6   // Operating LoRa frequency
#define SF      7     // Operating LoRa Spread Factor
#define BAND  125E3   // Operating LoRa Bandwidth
#define TXPOWER 20    // Operating LoRa Transmition Power
#define CODINGRATE 8  // LoRa Coding Rate (between 4 and 8)
#define SYNCWORD 0x2D // LoRa Sync Word (default is 0x12)
#define BAUD 2000000  // BAUD serial rate


#define ADS    0x48  // Address of the ADC measuring the motor and PV modules current

// Conversion Ratios (Voltage Divider)

const float DT1_RATIO = 19.333333333f; // atualizar com valores medidos dos resistores
const float DT2_RATIO = 4.970588235f; // atualizar com valores medidos dos resistores
const float DT3_RATIO = 28.5f; // atualizar com valores medidos dos resistores
const float DT4_RATIO = 1.564102564f; // atualizar com valores medidos de resistores
const float DT5_RATIO = 1.552971576f; // VOLTAGE DIVIDER FOR POTENTIOMETER

// Objects

String rssi = "RSSI --";
String packSize = "--";
String packet;

TinyGPSPlus gps;      // GPS object
HardwareSerial ss(2); // Hardware Serial comunication object

Adafruit_ADS1115 ads(ADS);

//   Cheatsheet                                                     ADS1115
//                                                                  -------
// ads.setGain(GAIN_TWOTHIRDS);  // 2/3x gain +/- 6.144V  1 bit =   0.1875mV (default)
// ads.setGain(GAIN_ONE);        // 1x gain   +/- 4.096V  1 bit =   0.125mV
// ads.setGain(GAIN_TWO);        // 2x gain   +/- 2.048V  1 bit =   0.0625mV
// ads.setGain(GAIN_FOUR);       // 4x gain   +/- 1.024V  1 bit =   0.03125mV
// ads.setGain(GAIN_EIGHT);      // 8x gain   +/- 0.512V  1 bit =   0.015625mV
// ads.setGain(GAIN_SIXTEEN);    // 16x gain  +/- 0.256V  1 bit =   0.0078125mV

// Variables
double boat_speed;

// functions

// Coisas do LCD
float screenDuration;
//ActualScreen = 0 (tela principal - Velocidade grande e powers)
//ActualScreen = 1 (Tela Potenciometro)
//ActualScreen = 2 (Low Battery screen)
//    ||       = 3 (Low Efficiency status)
byte ActualScreen;
bool temporaryScreen;
// necessario para caracteres grandes no LCD
// CHARS
byte chr0[8] = {
  B11111,
  B11111,
  B11111,
  B11111,
  B11111,
  B11111,
  B11111,
  B11111
};
byte chr1[8] = {
  B00000,
  B00000,
  B00000,
  B00000,
  B11111,
  B11111,
  B11111,
  B11111
};
byte chr2[8] =  {
  B11111,
  B11111,
  B11111,
  B11111,
  B00000,
  B00000,
  B00000,
  B00000
};
LiquidCrystal_I2C lcd(0x27, 20, 4);
// Cria numeros grandes
void num0(int i)
{
  lcd.setCursor(i, 0);
  lcd.write(0);
  lcd.setCursor(i + 1, 0);
  lcd.write(0);
  lcd.setCursor(i + 2, 0);
  lcd.write(0);
  lcd.setCursor(i, 1);
  lcd.write(0);
  lcd.setCursor(i + 2, 1);
  lcd.write(0);
  lcd.setCursor(i, 2);
  lcd.write(0);
  lcd.setCursor(i + 2, 2);
  lcd.write(0);
  lcd.setCursor(i, 3);
  lcd.write(0);
  lcd.setCursor(i + 1, 3);
  lcd.write(0);
  lcd.setCursor(i + 2, 3);
  lcd.write(0);
}

void num1(int i)
{
  lcd.setCursor(i + 1, 0);
  lcd.write(0);
  lcd.setCursor(i, 1);
  lcd.write(0);
  lcd.setCursor(i + 1, 1);
  lcd.write(0);
  lcd.setCursor(i + 1, 2);
  lcd.write(0);
  lcd.setCursor(i + 1, 3);
  lcd.write(0);
}

void num2(int i)
{
  lcd.setCursor(i, 0);
  lcd.write(0);
  lcd.setCursor(i + 1, 0);
  lcd.write(0);
  lcd.setCursor(i + 2, 0);
  lcd.write(0);
  lcd.setCursor(i, 1);
  lcd.write(1);
  lcd.setCursor(i + 1, 1);
  lcd.write(1);
  lcd.setCursor(i + 2, 1);
  lcd.write(0);
  lcd.setCursor(i, 2);
  lcd.write(0);
  lcd.setCursor(i + 1, 2);
  lcd.write(2);
  lcd.setCursor(i + 2, 2);
  lcd.write(2);
  lcd.setCursor(i, 3);
  lcd.write(0);
  lcd.setCursor(i + 1, 3);
  lcd.write(0);
  lcd.setCursor(i + 2, 3);
  lcd.write(0);
}

void num3(int i)
{
  lcd.setCursor(i, 0);
  lcd.write(0);
  lcd.setCursor(i + 1, 0);
  lcd.write(0);
  lcd.setCursor(i + 2, 0);
  lcd.write(0);
  lcd.setCursor(i, 1);
  lcd.write(1);
  lcd.setCursor(i + 1, 1);
  lcd.write(1);
  lcd.setCursor(i + 2, 1);
  lcd.write(0);
  lcd.setCursor(i, 2);
  lcd.write(2);
  lcd.setCursor(i + 1, 2);
  lcd.write(2);
  lcd.setCursor(i + 2, 2);
  lcd.write(0);
  lcd.setCursor(i, 3);
  lcd.write(0);
  lcd.setCursor(i + 1, 3);
  lcd.write(0);
  lcd.setCursor(i + 2, 3);
  lcd.write(0);
}

void num4(int i)
{
  lcd.setCursor(i, 0);
  lcd.write(0);
  lcd.setCursor(i + 2, 0);
  lcd.write(0);
  lcd.setCursor(i, 1);
  lcd.write(0);
  lcd.setCursor(i + 1, 1);
  lcd.write(1);
  lcd.setCursor(i + 2, 1);
  lcd.write(0);
  lcd.setCursor(i, 2);
  lcd.write(2);
  lcd.setCursor(i + 1, 2);
  lcd.write(2);
  lcd.setCursor(i + 2, 2);
  lcd.write(0);
  lcd.setCursor(i + 2, 3);
  lcd.write(0);
}

void num5(int i)
{
  lcd.setCursor(i, 0);
  lcd.write(0);
  lcd.setCursor(i + 1, 0);
  lcd.write(0);
  lcd.setCursor(i + 2, 0);
  lcd.write(0);
  lcd.setCursor(i, 1);
  lcd.write(0);
  lcd.setCursor(i + 1, 1);
  lcd.write(1);
  lcd.setCursor(i + 2, 1);
  lcd.write(1);
  lcd.setCursor(i, 2);
  lcd.write(2);
  lcd.setCursor(i + 1, 2);
  lcd.write(2);
  lcd.setCursor(i + 2, 2);
  lcd.write(0);
  lcd.setCursor(i, 3);
  lcd.write(0);
  lcd.setCursor(i + 1, 3);
  lcd.write(0);
  lcd.setCursor(i + 2, 3);
  lcd.write(0);
}
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

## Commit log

2019-04-21 Added first transmission prototype, shows signal and packet via Serial
2019-06-08 Added analog to digital sketch using a ADS1115 board
2019-06-11 Added a simpler version of the ADS1115 circuit code. Working
2019-06-13 Tweaked the print
2019-07-06 Added efficiency tracking, renamed the sender to transmitter and fixed the message for testing purposes
    [receiver.ino, transmitter.ino]
2019-07-31 Update photovoltaic.ino
    Atualizacao de um comentario
2019-07-31 circuito update
    circuito com medicao das bombas e bateria
2019-09-01 adding telemetria PCB
    not concluded
    [pcb_telemetria.brd, pcb_telemetria.sch]
2019-09-03 update
    adicao de rotas na pcb
    [pcb_telemetria.brd, pcb_telemetria.sch]
2019-09-04 Adicao de Rotas e mudanca de nomes
    [pcb_telemetria.brd, pcb_telemetria.sch]
2019-09-04 ultima ligacao nao GND
    [pcb_telemetria.brd]
2019-09-10 battery_discharge code
    Code for the ads to the battery discharge test.
2019-09-10 valores das resistencias (att)
    update
2019-09-13 Analise do teste de baterias
    Código do teste das baterias finalizado
2019-09-18 up caqui
    aa
    [pcb_telemetria_caqui.sch]
2019-09-21 primeira versao placa
    [pcb_telemetria.brd, pcb_telemetria_caqui.sch]
2019-10-02 Changes in the board and code
    mudancas no codigo e placa
    [pcb_telemetria_caqui.brd, pcb_telemetria_caqui.sch]
2019-10-02 ultima att
    up
    [pcb_telemetria_caqui.brd, pcb_telemetria_caqui.sch]
2019-10-03 att nos pinos e adicao de regulador pwm
    tired
    [pcb_telemetria_caqui.brd, pcb_telemetria_caqui.sch]
2019-10-03 Erro no código
    A porta enable estava setada no pino errado (4 e esta é a de signal), mudei para 23. No entanto no código em nenhum momento enable é definida (nem como low nem como high).
2019-10-03 Placa finalizada, aguardando ajustes
    Finalizou-se o roteamento pre testes. Aguardando testes para realização de ajustes.
    [pcb_telemetria_caqui.brd, pcb_telemetria_caqui.sch]
2019-10-03 Limpeza e mudanca dos nomes
    Update de organizacao
    [pcb_telemetria.brd, pcb_telemetria.sch, pcb_telemetria_caqui.brd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]
2019-10-05 updating the code
    Att code to be aligned with the board
2019-10-05 organizing current folder
    [pcb_telemetria.brd, pcb_telemetria.sch]
2019-10-07 Att in the rate of resistores (adding DT5_RATIO)
2019-10-09 Schematic e code conforming
    The mux pins in the code are now updated (EN on the ground rsrs) and the circuit project are already routed with the new mux pins
    [pcb_telemetria.brd, pcb_telemetria.sch]
2019-10-09 BUTTON LOGIC FIX
    Updating the logic on the button response.
    [transmitter.ino]
2019-10-09 mudancas na placa
    resistores atualizados com sucesso
    [pcb_telemetria.brd, pcb_telemetria.sch]
2019-10-10 update
    Delay in muxChannel.. maybe too much. I need to test what is the minimum required for good performance.
    [transmitter.ino]
2019-10-10 Updates and test code
    fixing the logic number (4096 to 4095)
    [transmitter.ino]
2019-10-12 Um ads 1115 que presta
2019-10-12 adicionei o ADC interno
2019-10-18 testando adc
2019-10-19 commit dente de serra
2019-10-20 logs ADC reads
    Different kinds of inputs in adc pin.
2019-10-20 adc ajustado
2019-10-27 Organazing
    Change some bad names and adding the cell and multiplexed type.
    [pcb_telemetria.brd, pcb_telemetria.sch]
2019-11-15 jlcpcb added
    [pcb_telemetria.brd, pcb_telemetria.sch]
2019-11-15 placa com trilhas finas e Mini-fit molex
    [pcb_telemetria.brd, pcb_telemetria.sch]
2019-11-21 adicao de conexao para pinos extras
    [pcb_telemetria.brd, pcb_telemetria.sch]
2019-11-26 Moved some files and deleted thrash
    [pcb_telemetria.brd, pcb_telemetria.sch]
2019-12-14 adding connector to sd card and capacitors
    [pcb_telemetria.brd, pcb_telemetria.sch]
2019-12-14 adding connector to sdcard and ground plane
    [pcb_telemetria.brd, pcb_telemetria.sch]
2019-12-16 PCB to print in ERUS
    [pcb_telemetria.brd, pcb_telemetria.sch]
2019-12-26 att pra caqui baixar
    ice crackerr
    [pcb_telemetria.brd]
2019-12-26 veja agora ice
    [pcb_telemetria.brd, pcb_telemetria.sch]
2019-12-26 voltando com a tinyGPS
2019-12-27 removendo para futuro merge
    [pcb_telemetria.brd, pcb_telemetria.sch]
2019-12-27 Arrumando o que o agricio faz 🙊
    [pcb_telemetria.brd, pcb_telemetria.sch]
2019-12-27 removing latest and changing obsolete folder
    [pcb_telemetria.brd, pcb_telemetria.sch]
2019-12-27 Bringing things out from latest
    [pcb_telemetria_inicial.brd, pcb_telemetria_inicial.sch, pcb_telemetria_jlcpcb.brd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]
2019-12-27 changes to merge
    [pcb_telemetria.brd, pcb_telemetria.sch]
2019-12-27 removendo "circuit"
2019-12-30 Receiving and writing serial data
    [dados.csv]
2020-01-03 up_no important changes
    [pcb_telemetria_wide.brd]
2020-01-06 plaquinha extra pro painel
    [placa_painel.sch]
2020-01-13 increased of vias diameter
    [placa_painel.brd]
2020-01-28 Data viz update
    [dados.csv]
2020-01-29 Fixed sync word bug
    [transmitter.ino]
2020-01-29 First day of tests, logs added
    [2020-01-2916:15:21.csv, 2020-01-2916:15:41.csv, 2020-01-2916:45:15.csv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]
2020-01-29 Mudancas nos prints
    Removing some Serial.Print's (even if were just comments)
2020-01-30 Changed log names and script to make it windows friendly
    [2020-01-29_16-15-21.csv, 2020-01-29_16-15-41.csv, 2020-01-29_16-45-15.csv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]
2020-01-30 Adding ACS code and removing some
    Useless lora prints removed
    [pcb_telemetria_wide.brd]
2020-01-30 att receiver header and getting back reverse
    [receiver.ino, transmitter.ino]
2020-01-30 Fixed the CSV delimiter parameter
    [2020-01-30_22-27-34.csv, 2020-01-30_22-29-18.csv]
2020-01-30 changing infos about prints
2020-01-30 Fixed header printing without \n
    [receiver.ino]
2020-01-31 corrections in mux pins defined and list
    [receiver.ino, transmitter.ino]
2020-01-31 Added LCD Alternative Technical Resourse (ATR, for short) arduino code
    [2020-01-30_23-02-19.csv, 2020-01-30_23-09-40.csv, 2020-01-30_23-09-50.csv]

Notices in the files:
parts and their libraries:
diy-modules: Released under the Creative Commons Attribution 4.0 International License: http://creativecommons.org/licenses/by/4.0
